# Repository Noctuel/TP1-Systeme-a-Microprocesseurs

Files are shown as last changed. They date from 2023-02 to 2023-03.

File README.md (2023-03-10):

# Domingo Dorian - SIMOES Raphael - TP1-Systeme-a-Microprocesseurs
# 1.1 Création de la structure du projet
6. Activez l’USART2 en mode Asynchrone. Gardez les paramètres par défaut, et notez le baud rate
=> baud rate 115200 Bits/s

# 1.2 Le microcontrôleur sous KiCAD
13. Pourquoi PB9 est relié à la masse ?
=>Cela permet de choisir le boot ici relier à la masse cela permet de boot sur la flash.
14. Quel est le rôle de L1, C5 et C7 ?
=>Il s'agit d'un filtre de la tension d'alimentation pour obtenir une tension d'alimentation pour l'ADC car ce composant est plus sensible
=> Il  y a deux capacité la petite filtre les petites variations et la grande les grandes variation
=> L'inductance est utiliser à la place d'une résistance pour éviter une chute de tension.

# 1.3 Le reste du schéma
3. Quelle page de la datasheet indique les valeurs des condensateurs ?
=> page 3 "Recommended Operating Conditions"
5. Quelle page de la datasheet nous indique les valeurs de condensateurs ?
=> Digital Pin Capacitance page 6
6. Quel est le rôle de la broche CS ?
=>C'est le Chip Select actif à l'état bas qui permet d'activer/choisir le composant
7. Quel est le rôle de la broche LDAC ?
=>Il sert à transférer le registre d'entré à celui de sortie si il est à 0. On peut le piloter pour si on veux synchroniser plusieur DAC
8. Pourquoi le signal MISO n’est pas utilisé ?
=> Car le DAC ne répond pas au µp
10. Où trouve-t-on les indications du pinout du connecteur SWD ?
On les trouve dans la datasheet du stlink3set il s'agit d'une recopie du connecteur STDC14 c'est à dire le connecteur JTAG qui permet de reprogrammer le µp avec le protocole SWD

# 1.4 Affectation des empreintes
3. Que signifie 0805 ? 0603 ? 1206 ?
=> il s'agit des taille des composant (largeur / longueur)
4. Que signifie LQFP ? SOT-223 ? SOIC ? Ne vous contentez pas de donner le sigle,j’attends une petite description (vous pouvez copier-coller depuis wikipedia, mais lisez avant quand même))
=> LQFP : Low Profile Quad Flat Package
En électronique, Quad Flat Package (QFP) est un type de boîtier de circuit intégré destiné à être directement soudé sur circuit imprimé. Ce boîtier est normalisé suivant la JEDEC1
Le boîtier rectangulaire (en plastique ou en céramique) est doté de broches de connexion sur ses 4 côtés (jusqu'à 200 broches). Les broches sont généralement espacées de 0,4 à 1 mm, et sont extérieures au boîtier contrairement aux QFN.
=> SOT-223 : Il s'agit d'un réguleur de tension LDO
=> small outline integrated circuit : Circuit intégré en boîtier à dimension réduite présentant des connexions en aile de mouette sur deux rangées.

# 3.1 Activation des LL drivers
2. Regardez les fichiers générés. Quelles sont les différences ?
=> En paramètrant avec LL on utilise les fonctions du meme nom qui sont moins lourd par exemple stm32l0xx.ll.usart.c fais 400 ligne contre 4000 pour sont équivalent en HAL
=> On doit utiliser ces fonctions car notre processeur n'aura pas assez de mémoire

4. Que signifie __STATIC_INLINE ?
=>Inline veut dire que la fonction n'est pas une réel fonction mais que l'on va recopier son code à l'endroit ou on la appeler
5. Et pourquoi y a-t-il du code dans un .h alors que Môssieur Fiack vous a expres-sément demandé de pas le faire ? (Les deux questions sont peut-être liés, va savoir)
=> C'est justement a cause de Inline que l'on écrit dans le header

# 3.2 LED simple
2. On compte de 0 à 255 on a donc une fréquence de 32 000 000 /256 = 125 000 Hz. On doit donc avoir un prescaler de 125-1 (on compte de 0)
8. Le fonctionnement a été validé par l'enseignant.

# 3.3 LED avec timer
3. On peut laisser PSC à 0 et seuleument mettre ARR à 32 000-1(on compte de 0) pour obtenir notre fréquence de 1 kHz (32 000 000/32 000=1 000 Hz).
6. Dans"stm32l0xx_it.c"
7. Il manque la fonction qui retire l'interuption
8. On reste bloqué indéfinement dans l'interuption
9. Appeler immidiatement la fonction du timer qui retire le flag dans notre fonction d'interruption du Timer
11. Le fonctionnement a été validé par l'enseignant.

# 3.4 UART, un simple echo

5. Il manque & à ch pour passer l'adresse de ch

6. Le fonctionnement a été validé par l'enseignant.

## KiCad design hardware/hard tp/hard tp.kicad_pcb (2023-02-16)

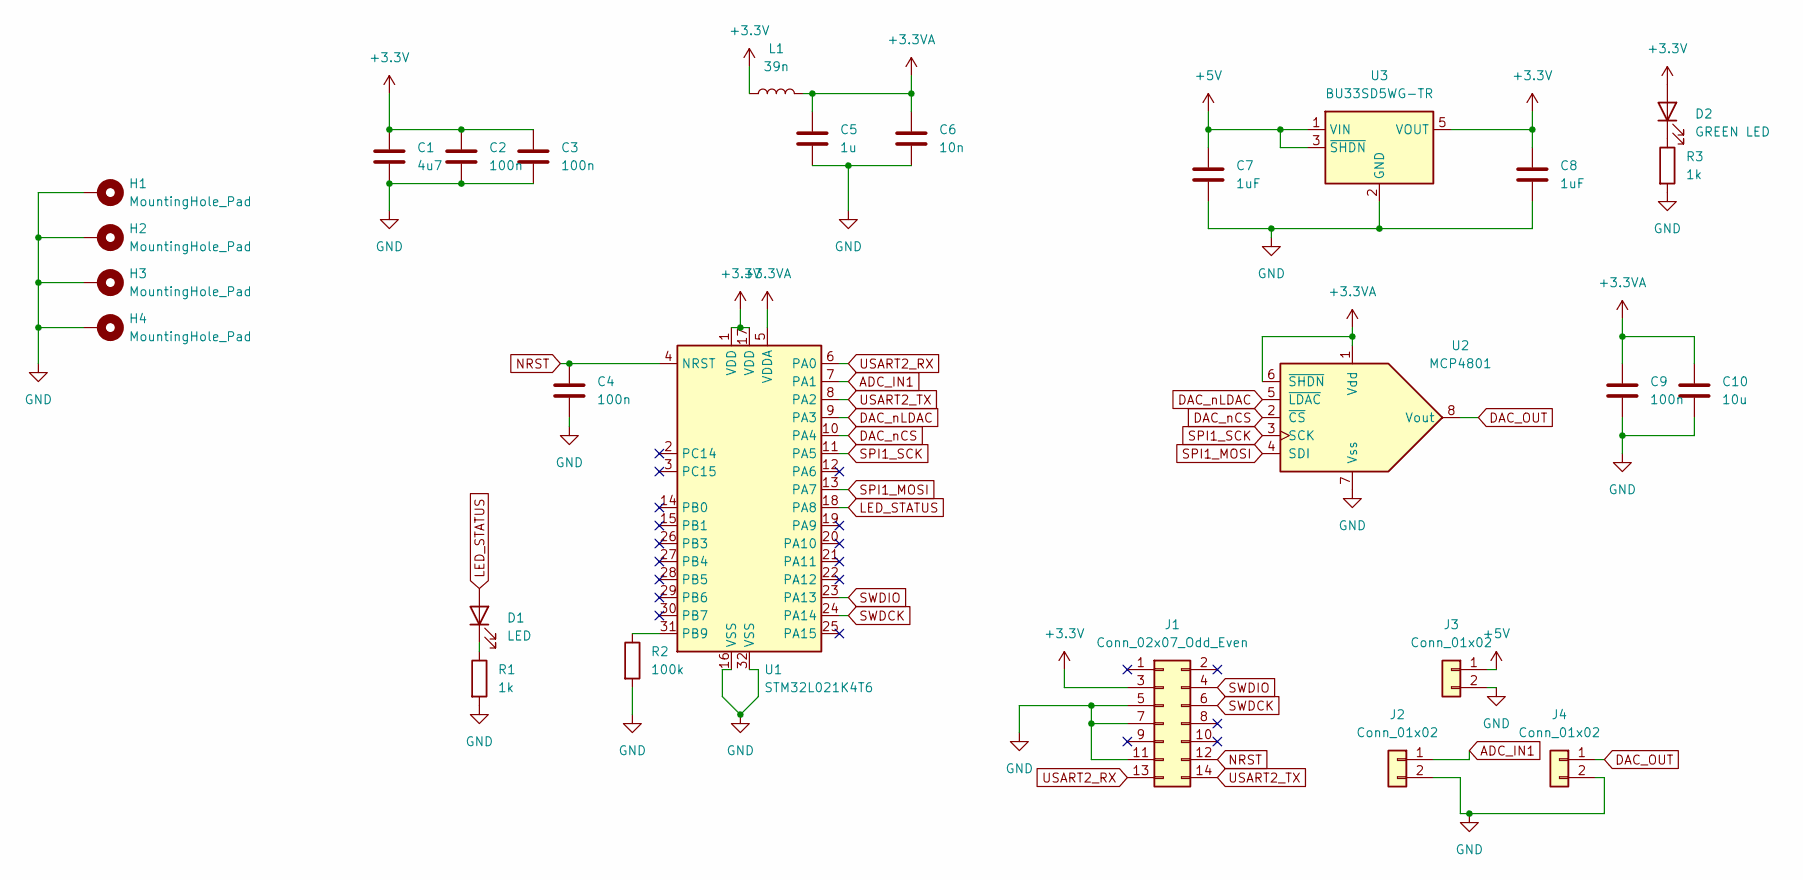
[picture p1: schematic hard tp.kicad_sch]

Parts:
C1: 4u7; C_0805_2012Metric_Pad1.18x1.45mm_HandSolder
C2, C3, C4, C9: 100n; C_0805_2012Metric_Pad1.18x1.45mm_HandSolder
C5: 1u; C_0805_2012Metric_Pad1.18x1.45mm_HandSolder
C6: 10n; C_0805_2012Metric_Pad1.18x1.45mm_HandSolder
C7, C8: 1uF; C_0805_2012Metric
C10: 10u; C_0805_2012Metric
D1: LED; LED_0603_1608Metric_Pad1.05x0.95mm_HandSolder
D2: GREEN LED; LED_0603_1608Metric_Pad1.05x0.95mm_HandSolder
H1, H2, H3, H4: MountingHole_Pad; MountingHole_3.2mm_M3_Pad
J1: Conn_02x07_Odd_Even; PinHeader_2x07_P1.27mm_Vertical_SMD
J2, J3, J4: Conn_01x02; JST_XH_B2B-XH-A_1x02_P2.50mm_Vertical
L1: 39n; L_0805_2012Metric_Pad1.05x1.20mm_HandSolder
R1, R3: 1k; R_0805_2012Metric_Pad1.20x1.40mm_HandSolder
R2: 100k; R_0805_2012Metric_Pad1.20x1.40mm_HandSolder
U1: STM32L021K4T6; LQFP-32_7x7mm_P0.8mm
U2: MCP4801; SOIC-8_3.9x4.9mm_P1.27mm
U3: BU33SD5WG-TR; SOT-23-5

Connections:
+3.3V: C1.1, C2.1, C3.1, C8.1, D2.2 (A), J1.3, L1.1, U1.1 (VDD), U1.17 (VDD), U3.5 (VOUT)
+3.3VA: C5.1, C6.1, C9.1, C10.1, L1.2, U1.5 (VDDA), U2.1 (Vdd), U2.6 (~SHDN)
+5V: C7.1, J3.1, U3.1 (VIN), U3.3 (~SHDN)
ADC_IN1: J2.1, U1.7 (PA1)
DAC_OUT: J4.1, U2.8 (Vout)
DAC_nCS: U1.10 (PA4), U2.2 (~CS)
DAC_nLDAC: U1.9 (PA3), U2.5 (~LDAC)
GND: C1.2, C2.2, C3.2, C4.2, C5.2, C6.2, C7.2, C8.2, C9.2, C10.2, H1.1, H2.1, H3.1, H4.1, J1.5, J1.7, J1.11, J2.2, J3.2, J4.2, R1.2, R2.2, R3.2, U1.16 (VSS), U1.32 (VSS), U2.7 (Vss), U3.2 (GND)
LED_STATUS: D1.2 (A), U1.18 (PA8)
NRST: C4.1, J1.12, U1.4 (NRST)
unnamed: D1.1 (K), R1.1
unnamed: D2.1 (K), R3.1
unnamed: R2.1, U1.31 (PB9)
SPI1_MOSI: U1.13 (PA7), U2.4 (SDI)
SPI1_SCK: U1.11 (PA5), U2.3 (SCK)
SWDCK: J1.6, U1.24 (PA14)
SWDIO: J1.4, U1.23 (PA13)
USART2_RX: J1.13, U1.6 (PA0)
USART2_TX: J1.14, U1.8 (PA2)

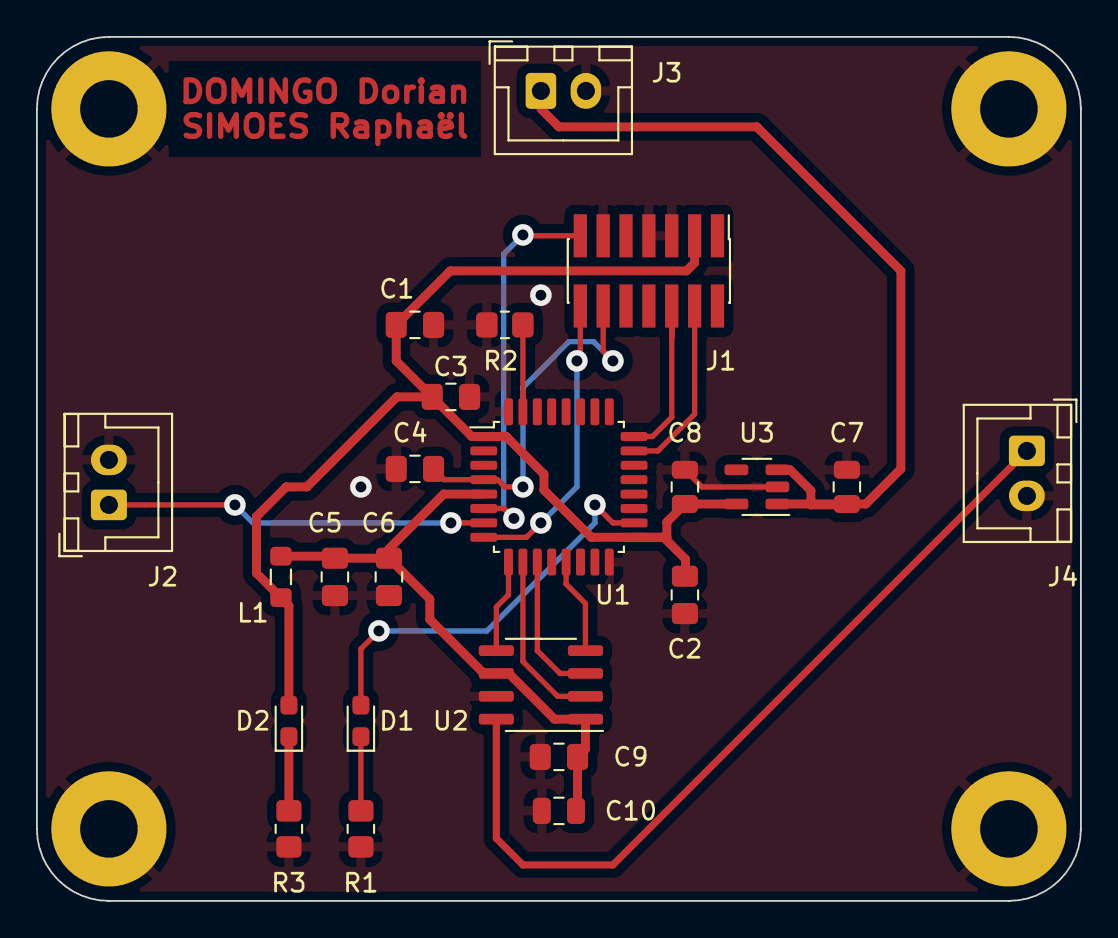
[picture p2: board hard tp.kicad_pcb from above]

Board: 2 copper layers, 58.0 x 48.0 mm, 27 parts (0 on the bottom side), 19 nets.

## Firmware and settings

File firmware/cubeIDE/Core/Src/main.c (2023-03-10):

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
/* Includes ------------------------------------------------------------------*/
#include "main.h"
#include "adc.h"
#include "spi.h"
#include "tim.h"
#include "usart.h"
#include "gpio.h"

/* USER CODE BEGIN Includes */
#include "Led.h"
#include "TimeBase.h"
#include "Serial.h"
/* USER CODE END Includes */


/* USER CODE BEGIN PV */
TIMER_LED TIM2_LED= {
		.lum = 0,
		.inc = 0,
		.timer = TIM2,
		.channel = LL_TIM_CHANNEL_CH1
};
/* USER CODE END PV */

void SystemClock_Config(void);
/**
 * @brief  The application entry point.
 * @retval int
 */
int main(void)
{
	/* MCU Configuration--------------------------------------------------------*/

	/* Reset of all peripherals, Initializes the Flash interface and the Systick. */
	LL_APB2_GRP1_EnableClock(LL_APB2_GRP1_PERIPH_SYSCFG);
	LL_APB1_GRP1_EnableClock(LL_APB1_GRP1_PERIPH_PWR);

	/* SysTick_IRQn interrupt configuration */
	NVIC_SetPriority(SysTick_IRQn, 3);

	/* Configure the system clock */
	SystemClock_Config();

	/* Initialize all configured peripherals */
	MX_GPIO_Init();
	MX_USART2_UART_Init();
	MX_ADC_Init();
	MX_SPI1_Init();
	MX_TIM2_Init();
	MX_TIM21_Init();
	/* Infinite loop */
	/* USER CODE BEGIN WHILE */
	LedStart(&TIM2_LED);
	TimeBaseStartIT(); // active interruption
	char ch = 'a';
	while (1)
	{
		//Timer Seul
		//LedPulse(&TIM2_LED);
		//LL_mDelay(1);

		//Timer + interruption

		//UART Simple Echo
		ch = SerialReceiveChar(USART2);

		SerialTransmit(&ch, 1,USART2);

		/* USER CODE END WHILE */

		/* USER CODE BEGIN 3 */
	}
	/* USER CODE END 3 */
}

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


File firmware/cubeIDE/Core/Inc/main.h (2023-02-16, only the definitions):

#define DAC_nLDAC_Pin LL_GPIO_PIN_3
#define DAC_nLDAC_GPIO_Port GPIOA
#define DAC_nCS_Pin LL_GPIO_PIN_4
#define DAC_nCS_GPIO_Port GPIOA
#define NVIC_PRIORITYGROUP_0         ((uint32_t)0x00000007) /*!< 0 bit  for pre-emption priority,
#define NVIC_PRIORITYGROUP_1         ((uint32_t)0x00000006) /*!< 1 bit  for pre-emption priority,
#define NVIC_PRIORITYGROUP_2         ((uint32_t)0x00000005) /*!< 2 bits for pre-emption priority,
#define NVIC_PRIORITYGROUP_3         ((uint32_t)0x00000004) /*!< 3 bits for pre-emption priority,
#define NVIC_PRIORITYGROUP_4         ((uint32_t)0x00000003) /*!< 4 bits for pre-emption priority,

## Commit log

2023-02-15 add firmware
    [hard tp.kicad_pcb, hard tp.kicad_sch]
2023-02-15 modif final séance 1
    [hard tp.kicad_sch]

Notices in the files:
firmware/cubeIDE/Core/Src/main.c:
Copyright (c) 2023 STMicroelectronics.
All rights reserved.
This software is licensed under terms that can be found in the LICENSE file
